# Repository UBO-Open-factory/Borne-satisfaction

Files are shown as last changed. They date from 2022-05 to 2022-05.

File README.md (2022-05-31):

# The project #
This french project consists in making a terminal with 3 push buttons that can record the data on an SD card to collect results for a satisfaction survey.

You can find the project's page on [wikifactory](https://wikifactory.com/+uboopenfactory/borne-de-satisfaction)

Last : most of the documentation is written in French...

# Directory structure #

## Electronique
You can find here the Eagles project and everything about the mother board constuction.

## Mécanique
You can find here everything about the constuction of the wood-box as Lasercut plans.

Plans are on SVG format.

## Programmation
This is where you will find the main program, tests and everything about the ESP-32 code.

Code is written in C++ Language for a Firebeetle ESP32. Please [check the documentation before compiling](./Programmation/Microcontroleur/README.md).

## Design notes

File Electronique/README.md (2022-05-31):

L'électronique de la borne de satisfaction s'articule autour de l'architecture composée :
- Une carte Firebeetle ESP32 (Processeur+Charge de la batterie) <br>
- 3 Boutons poussoirs pour le vote
- 3 Leds pour indiquer le bouton pressé au votant
- Un lecteur de carte SD et sa carte SD qui contient les résultats des votes
- Une horloge temps réelle pour indiquer l'horodatage des votes

### Architecture Principale ###
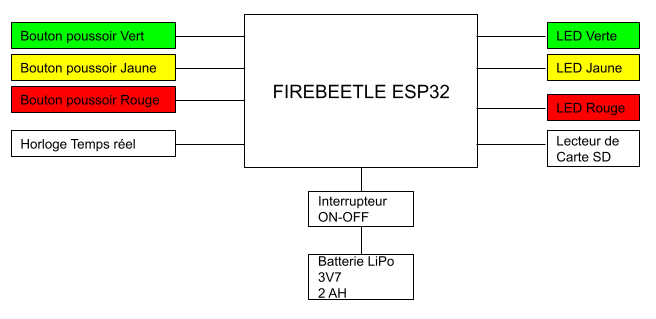
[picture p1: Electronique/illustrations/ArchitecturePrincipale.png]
Architecture Principale


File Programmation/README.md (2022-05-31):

Here you can find directories containing :

**doc** : the technical documetation of the ESP32 code (from Doxygen) in HTML format.

**Main program** : ESP32 programms

**tests** : Unit test for all the modules used on the mother board (SD card, DeepSleep, Leds, Littelfs, RTC ).

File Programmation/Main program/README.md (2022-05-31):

* TOC
{:toc}

---

# Compilation du programme #
Afin de pouvoir compiler le programme, il est nécessaire d'installer [l'IDE Arduino](https://www.arduino.cc/en/software) et les cartes ESP32.

## Installation des cartes ESP32 ##
Dans les préférences de l'IDE Arduino (Fichier>Préférences ou [Ctrl] + [,]), ajouter l'URL :
``` https://dl.espressif.com/dl/package_esp32_index.json ``` dans les URL de cartes suplémentaires (il est possible d'avoir plusieurs jeux de cartes, il faut les séparer par des virgules), comme sur l'image ci-dessous.
![Ajout des cartes ESP32](./illustrations/Arduino_preferences.png)

Ensuite, dans le menu Tools > Boards manager Recherchez "ESP32" et installez les cartes trouvées.
![Ajout des cartes ESP32](./illustrations/Arduino_ESP32.png)

Dans le menu Tools > Boards, choississez la carte **FireBeetle-ESP32**
![Choix de la carte ESP32](./illustrations/Arduino_CardChoice.png)

## Installation des librairies utiles à la compilation ##
Toutes les librairies utiles se [trouvent ici](./libs/README.md)

# Utilisation du programme #

Lors de sa première execution, le programme va générer un fichier de paramétrage vierge sur la carte SD. Une fois ce fichier modifié, vous pourrez :
- Mettre la borne à l'heure,
- Initialiser un ID pour la borne.
- Initialiser une question.

La borne est alors prète à enregistrer les réponses à la question. L'enregistrement se fait de plusieures façon dans différents fichiers stockés sur al acrte SD.

## Fichiers sur la carte SD ##
La carte SD contient plusieurs type de fichiers :
- Fichier de paramétrage (Modifiable par le **gestionnaire**)
- Fichier d'enregistrements des résultats (Généré par le programme).
- Fichier de synthèse des résultats (Généré par le programme).

### Format des fichiers ###

#### Fichier de paramétrage ####
fichier : **configuration.ini** formaté comme suit :
```
# Ceci est le fichier de configuration pour l'application 'Compteur de vote'.
# Ne modifiez pas le nom des variables (ce qui se trouve avant le signe egale sur une ligne).
# Vous pouvez modifier le texte se trouvant apres le signe egale a votre guise.
#____________________________________________________________________________________________
[config]

# Le siteID est votre identifiant comme il vous a ete donnee par l'enqueteur,
# ne le modifiez pas s'il ne vous le demande pas.
siteID=Cool Food UOF

# Cette phrase apparaitra dans le fichier resultat à votre questionnaire mais n'est pas visible sur la borne.
# Il est conseille de definir ici une phrase courte.
question=Aimez-vous faire des tests sur cette borne ?

# Si vous avez besoin de mettre la date à l'heure dans la borne, c'est ici.
# Pour la mise à l'heure, décommentez (supprimez le # en début de ligne) et 
# remplissez les champs suivant avec des valeurs numériques uniquement.
# Une fois la mise à l'heure faite, les lignes seront automatiquement commentées.
#year=2022
#month=04
#day=27
#hour=14
#minute=56
```

#### Fichier de synthèse ####
Fichier **YYYY-MM-DD_recap.txt** (par exemple 2022-04-27_recap.txt) formaté comme suit :

```
Etablissement = Cool Food I23I5V242Q
Date          = 2022/04/05
Question      = Voulez vous manger un plat végétarien une fois par semaine ?
Batterie      = 96%
Nombre d'appui sur les boutons :
  Rouge = 2
  Vert  = 4
  Jaune = 3
  TOTAL = 9
Pourcentage d'appui sur les boutons :
  Rouge = 22%
  Vert  = 44%
  Jaune = 33%

```

#### Fichiers CSV ####
Fichier **YYYY-MM-DD_detail.csv** (par exemple 2022-04-27_detail.csv) formaté comme suit :

Exemple d'un fichier 20220208_Mesures.csv

| ID du site | Date | Heure | Question | Vert | Rouge | Jaune | Niveau Batterie
| ---------- | ---- | ----- | -------- | --- | --- | ----------- | ---------------
| OpenFactory | 08/02/2022 | 12:45:52 | Aimez-vous les artichauds | 1 | 0 | 0 | 90%
| OpenFactory | 08/02/2022 | 12:45:53 | Aimez-vous les artichauds | 1 | 0 | 0 | 90%
| OpenFactory | 08/02/2022 | 12:45:55 | Aimez-vous les artichauds | 0 | 0 | 1 | 90%
| OpenFactory | 08/05/2022 | 20:12:15 | Aimez-vous les artichauds | 0 | 1 | 0 | 50%

## Codes couleur des LEDs ##
Les LEDS sont utilisées pour indiquer des alertes ou des erreurs lors de la mise sous tension de la borne.

| Couleur | Allumage LED  | Signification | Bloquant |
|---------|------|---------------|------|
| Rouge | Fixe | Carte SD manquante | Oui |
| Rouge | Clignotant | Fichier configuration manquante | Oui |
| Jaune | Bref | Niveau de batterie < 20% | Non  |
| Jaune | Clignotant | Niveau de batterie < 5% | Non  |
| Jaune | Clignotant (3x) | Echec de la mise à l'heure | Non  |
| Vert  | Clignotant (3x) | Date et heure mise à jour à partir du fichier de configuration | Non |
| Vert  | Bref | Tout est OK | Non |

## Algorithme du microcontrôleur ##
![Algorithme du microcontrôleur](./illustrations/Diagrams.png)

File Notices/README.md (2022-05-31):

Dans ce répertoire, se trouvent :
- la notice d'utilisation de la borne.
- la notice du plan de montage

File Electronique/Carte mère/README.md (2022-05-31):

## Plan carte mère ##
dans ce répertoie, se trouve tout ce qui conerne la fabrication de la carte mère fait pour le projet.

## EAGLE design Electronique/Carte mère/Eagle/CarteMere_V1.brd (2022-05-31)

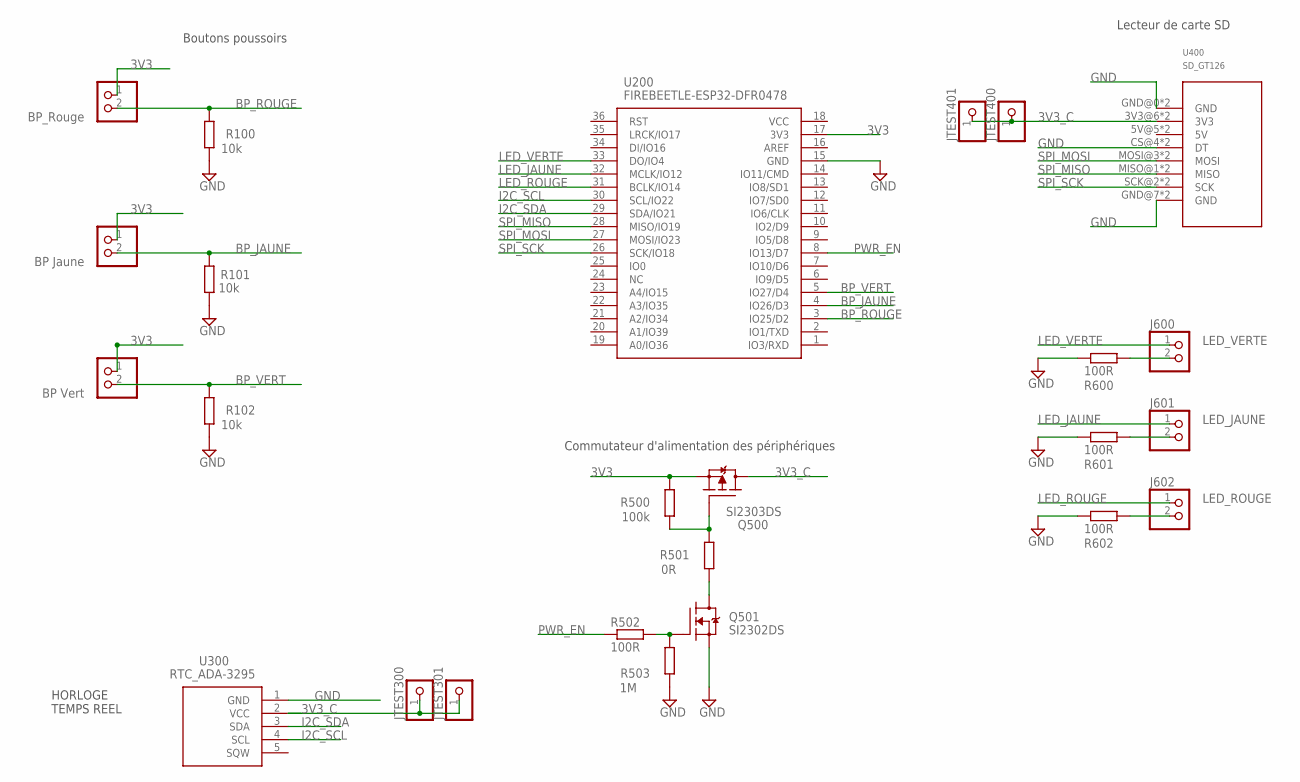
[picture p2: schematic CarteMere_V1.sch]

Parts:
J100: BP_Rouge; 1X02
J101: BP Jaune; 1X02
J102: BP Vert; 1X02
J600: LED_VERTE; 1X02
J601: LED_JAUNE; 1X02
J602: LED_ROUGE; 1X02
JTEST300, JTEST301, JTEST400, JTEST401: PINHD-1X1; 1X01
Q500: SI2303DS; SOT23
Q501: SI2302DS; SOT23
R100, R101, R102: 10k; 0207/10
R500: 100k; 0207/10
R501: 0R; 0207/10
R502, R600, R601, R602: 100R; 0207/10
R503: 1M; 0207/10
U200: FIREBEETLE-ESP32-DFR0478; FIREBEETLE_ESP32
U300: RTC_ADA-3295; ADA3295
U400: SD_GT126

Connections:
3V3: J100.1, J101.1, J102.1, Q500.2 (S), R500.2, U200.17 (3V3)
3V3_C: JTEST300.1, JTEST301.1, JTEST400.1, JTEST401.1, Q500.3 (D), U300.2 (VCC), U400.3V3@6 (3V3), U400.3V3@9 (3V3)
BP_JAUNE: J101.2, R101.2, U200.4 (IO26/D3)
BP_ROUGE: J100.2, R100.2, U200.3 (IO25/D2)
BP_VERT: J102.2, R102.2, U200.5 (IO27/D4)
DQ501: Q501.3 (D), R501.1
GND: Q501.2 (S), R100.1, R101.1, R102.1, R503.1, R600.1, R601.1, R602.1, U200.15 (GND), U300.1 (GND), U400.CS@4 (DT), U400.CS@11 (DT), U400.GND@0 (GND), U400.GND@7 (GND), U400.GND@8 (GND), U400.GND@15 (GND)
I2C_SCL: U200.30 (SCL/IO22), U300.4 (SCL)
I2C_SDA: U200.29 (SDA/IO21), U300.3 (SDA)
LED_JAUNE: J601.1, U200.32 (MCLK/IO12)
LED_ROUGE: J602.1, U200.31 (BCLK/IO14)
LED_VERTE: J600.1, U200.33 (DO/IO4)
unnamed: Q501.1 (G), R502.2, R503.2
unnamed: J600.2, R600.2
unnamed: J601.2, R601.2
unnamed: J602.2, R602.2
unnamed: Q500.1 (G), R500.1, R501.2
PWR_EN: R502.1, U200.8 (IO13/D7)
SPI_MISO: U200.28 (MISO/IO19), U400.MISO@1 (MISO), U400.MISO@14 (MISO)
SPI_MOSI: U200.27 (MOSI/IO23), U400.MOSI@3 (MOSI), U400.MOSI@12 (MOSI)
SPI_SCK: U200.26 (SCK/IO18), U400.SCK@2 (SCK), U400.SCK@13 (SCK)

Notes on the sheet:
HORLOGE TEMPS REEL
Commutateur d'alimentation des périphériques
Lecteur de carte SD
Boutons poussoirs

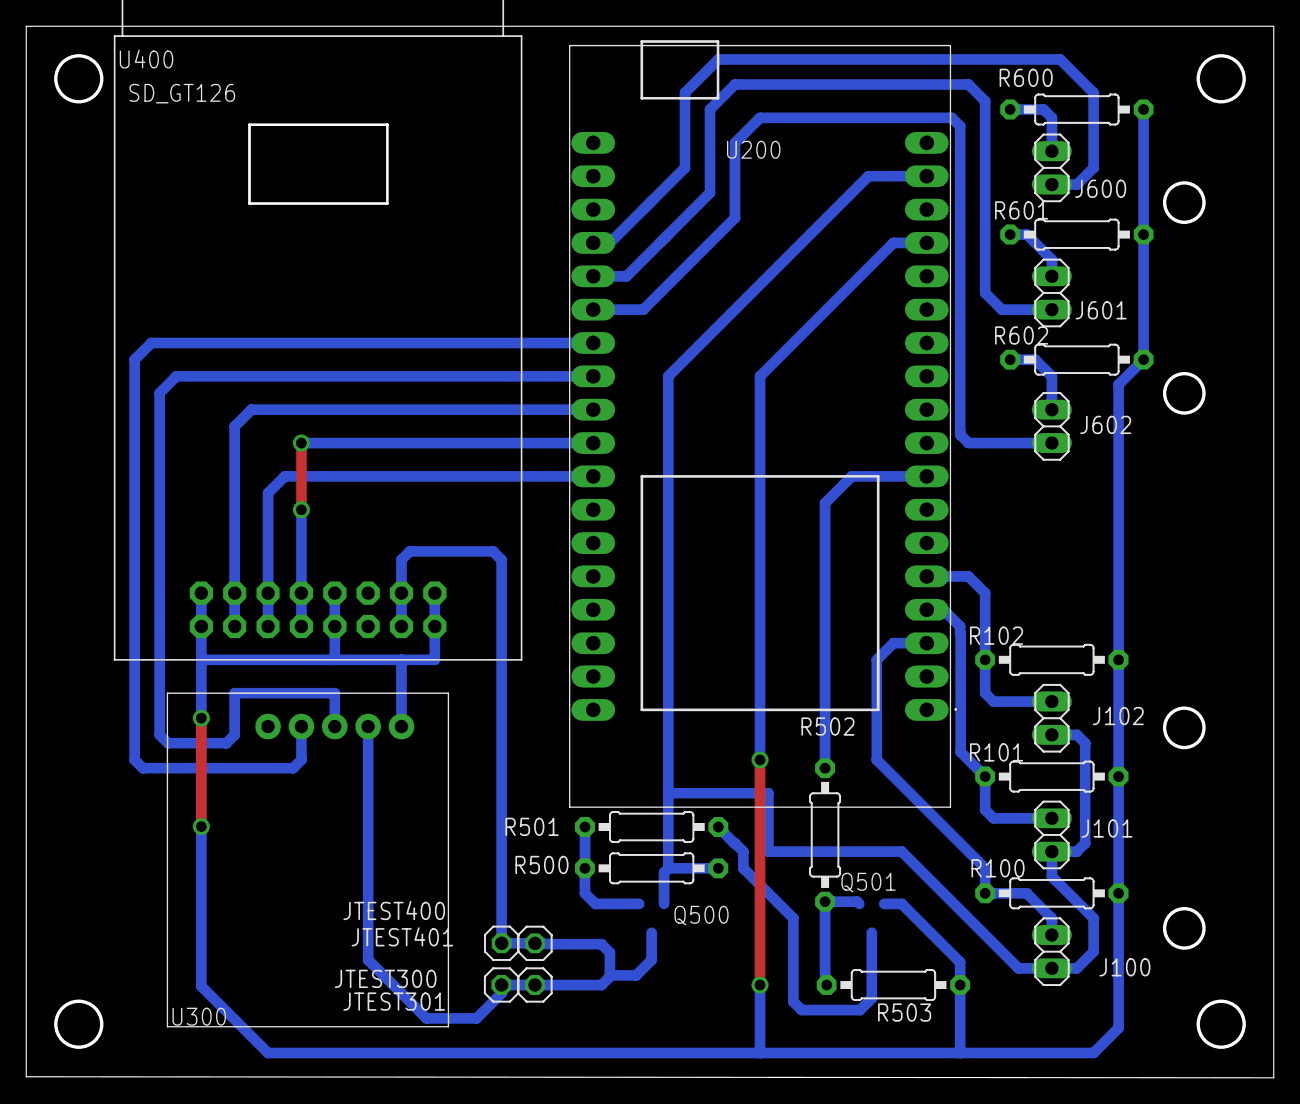
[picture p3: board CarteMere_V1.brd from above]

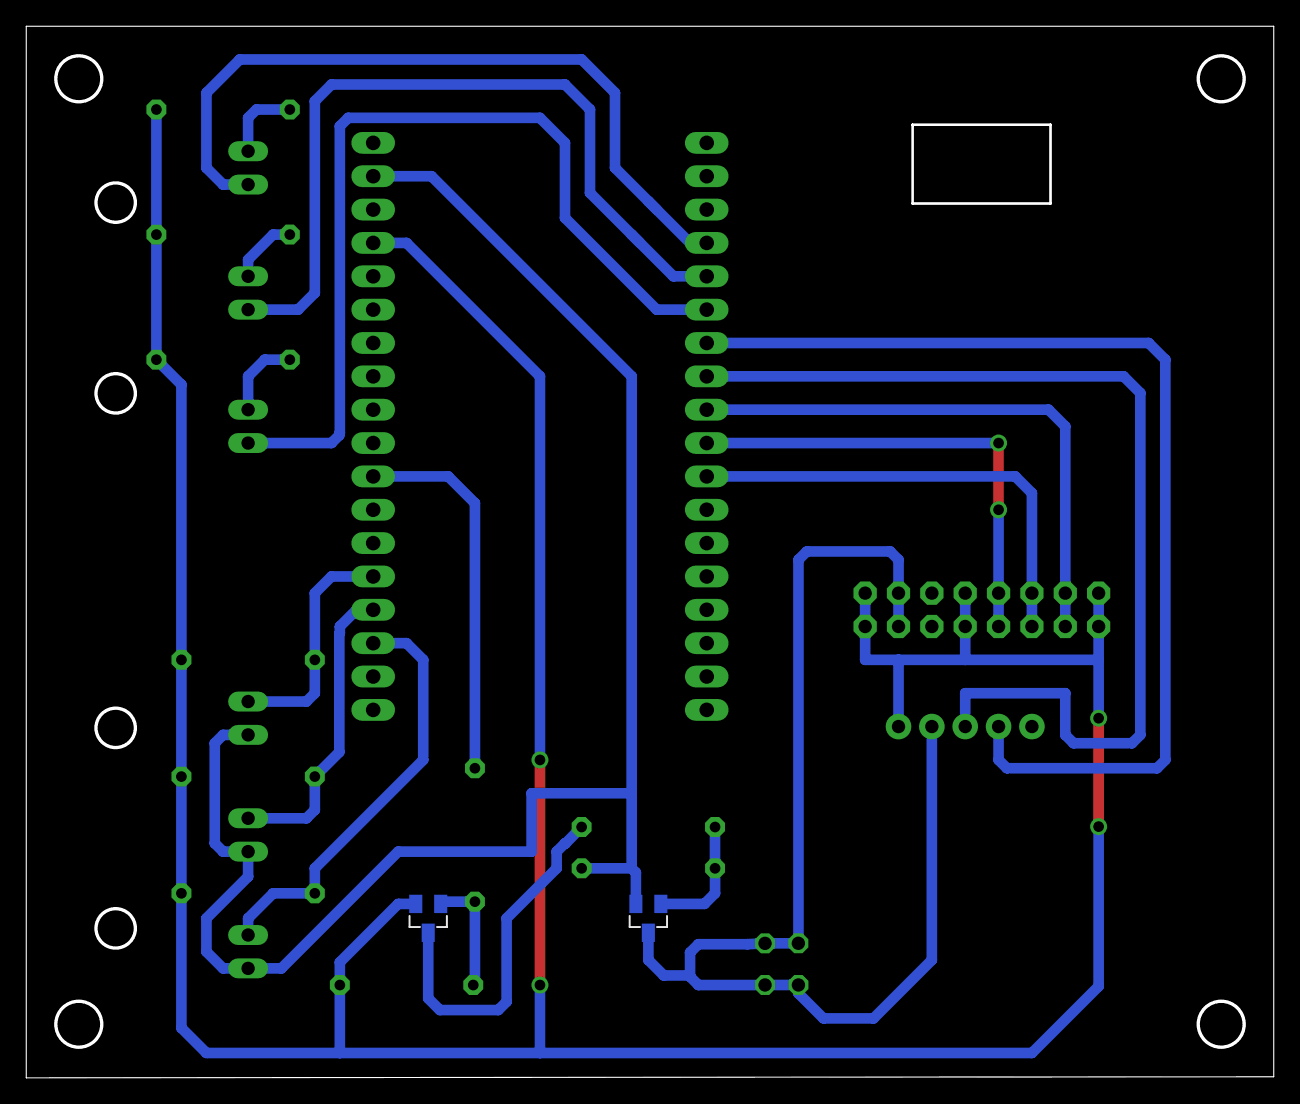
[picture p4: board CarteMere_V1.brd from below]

Board: 2 copper layers, 95.0 x 80.1 mm, 25 parts (2 on the bottom side), 21 nets.

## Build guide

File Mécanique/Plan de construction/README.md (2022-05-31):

## Plan de construction ##
Dans ce répertoie, se trouve tout ce qui concerne la construction physique.

## Epaisseurs des matériaux ##
* PMMA :
  * Dessus de la boite : 3 mm
* CTP peuplier :
  * Coté de la boite : 5 mm

## Paramétres des découpes laser ##
Ces paramètres sont valable pour la laser avec des miroirs propres.

| Matériau | Opération | Power | Speed | Remarque |
|---|---|---|---|---|
| PMMA 3 mm | Cut | 20 | 75 | |
| CTP Peuplier 5 mm | Cut | 100 | 45 | |
| CTP Peuplier 5 mm | Mark | 8 | 20 | Défocalisation à +2 mm |

## Agencement des découpes ##
Le logiciel [Deepnest](https://deepnest.io/) permet d'agencer avec un minimum de perte les différentes pièces à découper.

Dans le logiciel Deepnest :
- Importer le fichier svg.
- Cliquer sur le [+] en bas de page pour ajouter une "planche"
- Donner les dimensions en millimètres de la planche (par exemple 900 x 450), puis cliqueer sur [Add]
- Cocher la pièce nouvellement créé (elle doit être tout en bas de la liste) pour qu'elle soit défini comme "Sheet".
- Lancer la génération de l'agencement [Start Nest]
- ... et attendre ...
- Cliquer sur un des éléments dans la liste *best nests so far* des "trucs" colorés pour choisir le meilleur agencement.
(Attention à bien vérifier que toutes les pièces sont bien présentes dans l'agencement proposé -> cf *parts placed*)
- Exporter le plan de découpe au format SVG.

NB : Le logiciel Deepnest ne s'arrète jamais de calculer un meilleur agencement, il faut cliquer sur le bouton **"Stop nest"**

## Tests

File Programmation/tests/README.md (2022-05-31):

## tests ##
Dans ce répertoie, se trouve tout ce qui concerne les tests unitaires du programme du microcontroleur

| Programme | Fonctionnalité | Source |
|---|---|---|
| esp32-deep-sleep-wake-up | Test du wake up après un Deep sleep. | [microcontrollerslab](https://microcontrollerslab.com/esp32-deep-sleep-wake-up-sources-arduino-ide/) |
| leds | Test l'allumage des leds | - |
| carteSD | Test de la carte SD | [randomnerdtutorials](https://randomnerdtutorials.com/esp32-microsd-card-arduino/)
| RTC | Test de la RTC et mise à l'heure | - |
| LittleFS-ESP32c | Test du file system dans la ram disk | - |

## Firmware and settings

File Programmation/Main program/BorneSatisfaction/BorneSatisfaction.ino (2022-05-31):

/**
 * @file BorneSatisfaction.ino
 * @brief Main programm for ESP32 micro-controller
 * @details Ce programme permet de compter le nombre d'appui sur un bouton de vote.
   - La sauvegarde de chaque vote est faite dans un fichier CSV.
   - La sauvegarde du cumul de chaque vote est faite dans un fichier TXT.
 * @date 2022-05-10
 * @author Alexandre PERETJATKO (peretjatko@univ-brest.fr)
 * 
 * @version 1.0.6
 */ // ___________________________________________________________________________________

/**
 * @def ModeDeug
 * @brief Mode prod => commenter la ligne suivante
              pour faire en sorte que le port série ne soit pas initialisé, ce qui
              permet de gagner de la vitesse d'execution au boot.
 */
//#define ModeDebug


#include "initialisation.h"
#include "RTC.h"
#include "batterie.h"
#include "carteSD.h"
#include "deepsleep.h"

// Gestion des erreurs
boolean BOO_ProblemeBatterie;
boolean BOO_ProblemeCarteSD;
boolean BOO_FichierParamsManquant;
boolean BOO_Clignote;

unsigned long LNG_Timer;


void setup() {
  // -------------------------------------------------------------------------------------------------------------
  // Mise à jour de la frequence du CPU pour une meilleur longévité de la batterie
  setCpuFrequencyMhz(80);


  // -------------------------------------------------------------------------------------------------------------
  // initialisation des clignotements des LEDs pour la gestion d'erreurs.
  //
  BOO_ProblemeBatterie      = false;
  BOO_ProblemeCarteSD       = false;
  BOO_FichierParamsManquant = false;
  BOO_Clignote = false;

  int batterieLevel =  0;

  // -------------------------------------------------------------------------------------------------------------
  // initialisation de la liaison série.
  //
#ifdef ModeDebug
  Serial.begin(115200);
  delay(1000);  // On attend que le port serie soit initialisé
  DEBUG("OK, let's go _____________________________________________________________________________");
#endif

  // -------------------------------------------------------------------------------------------------------------
  // Initialisation des PIN
  //
  pinMode(LED_ROUGE,  OUTPUT);  // Pin du bouton rouge
  pinMode(LED_VERT,   OUTPUT);  // Pin du bouton vert
  pinMode(LED_JAUNE,  OUTPUT);  // Pin du bouton jaune
  pinMode(BTN_ROUGE,  INPUT_PULLUP);  // Pin du bouton rouge
  pinMode(BTN_VERT,   INPUT_PULLUP);  // Pin du bouton vert
  pinMode(BTN_JAUNE,  INPUT_PULLUP);  // Pin du bouton jaune
  pinMode(PIN_PWR_EN, OUTPUT);  // Pin de l'autorisation de l'alimentation des périphériques


  // -------------------------------------------------------------------------------------------------------------
  // Récupération de la cause du wake up
  //
  esp_sleep_wakeup_cause_t wakeupCause = esp_sleep_get_wakeup_cause();
  DEBUG("Wake up reason : " + String(wakeupCause) );



  // -------------------------------------------------------------------------------------------------------------
  // Alimentation des périphériques
  //
  digitalWrite(PIN_PWR_EN, HIGH);
  delay(20); // pour laisser à l'alimentation le temps de s'établir 20 ms mini
  SPI.begin();


  /** -------------------------------------------------------------------------------------------------------------
      A-t-on une mise sous tension ?
     (on fait les tests de bon fonctionnements)
  */
  if (wakeupCause != ESP_SLEEP_WAKEUP_EXT0
      and wakeupCause != ESP_SLEEP_WAKEUP_EXT1
      and wakeupCause != ESP_SLEEP_WAKEUP_TIMER
      and wakeupCause != ESP_SLEEP_WAKEUP_TOUCHPAD
      and wakeupCause != ESP_SLEEP_WAKEUP_ULP) {
    
    DEBUG("mise sous tension");
    
    // .......................................................................
    // Carte SD manquante
    //
    if (!SD.begin()) {
      DEBUG("Carte SD manquante");
      BOO_ProblemeCarteSD = true;

    } else {
      // .......................................................................
      // Fichier params manquant
      // (on test l'existance du fichier de configuration).
      //
      if (! CARTESD_existeFile( fileName_Config )) {
        DEBUG("Fichier params manquant");
        BOO_ProblemeCarteSD = true;
        BOO_Clignote = true;

        CARTESD_writeConfigFile( fileName_Config );

        CARTESD_EraseROMSynthese("question");

      } else {
        String siteID, question = "";
        if ( ! CARTESD_readConfigFile( fileName_Config, siteID, question ) ) {
          
          // Il y a eu un problème de lecture de fichier de config sur la carte SD
          DEBUG("Il y a eu un problème de lecture de variables dans le fichier de config sur la carte SD");

          CARTESD_writeConfigFile( fileName_Config );
          CARTESD_EraseROMSynthese("question");

          BOO_ProblemeCarteSD = true;
          BOO_Clignote = true;
        } else {

          // .......................................................................
          // on réinitialise les synthèses si la question a changée
          String question = "";
          if ( CARTESD_questionChange(question) ) {
            // Efface littelFS
            // et
            // Reinitialise les fichiers de synthese et de la question dans le LittelFS
            CARTESD_EraseROMSynthese(question);
            DEBUG("Reinitialisation des synthèses");

          } else {
            DEBUG("pas de changement dans la question");
          }

          // Lecture de la date et l'heure
          DEBUG("Lecture de la date et l'heure");
          bool erreurFormat = false;
          if ( CARTESD_updateDate(fileName_Config, erreurFormat)) {
            // initialisation de la RTC à partir du fichier de paramétrage
            DEBUG("initialisation de la RTC à partir du fichier de paramétrage");
            for ( int i = 0; i < 3; i++) {
              digitalWrite(LED_VERT, LOW);
              delay(DelayExtinctionLEDs/3);
              digitalWrite(LED_VERT, HIGH);
              delay(DelayExtinctionLEDs/3);
            }
          } else {
            if( erreurFormat ){
              DEBUG("Erreur de format de date ou d'heure dans '"+ String(fileName_Config) +"' à l'initialisation de la RTC");
              for ( int i = 0; i < 3; i++) {
                digitalWrite(LED_JAUNE, HIGH);
                delay(DelayExtinctionLEDs);
                digitalWrite(LED_JAUNE, LOW);
                delay(DelayExtinctionLEDs);
              }
            }

          }

          // Extinction LEDs
          digitalWrite(LED_VERT, LOW);
          digitalWrite(LED_JAUNE, LOW);




          // .......................................................................
          // Batterie faible
          //
          batterieLevel = BATTERIE_getBatterieLevel();
          if (batterieLevel < 20) {
            DEBUG("Batterie faible");
            BOO_ProblemeBatterie = true;

            if (batterieLevel < 5) {
              DEBUG("Batterie Tres faible");
              BOO_Clignote = true;
            }


          } else {

            // .......................................................................
            // Tout est ok
            //
            DEBUG("Tout est ok");
            // Allumage LED verte
            digitalWrite(LED_VERT, HIGH);
            delay( DelayExtinctionLEDs);


            // Deep sleep
            DEEPSLEEP_start();
          }
        }
      }
    }
  } else {
    /** -------------------------------------------------------------------------------------------------------------
       On vient de réveiller la borne en appuyant sur un des boutons
    */
    // .......................................................................
    //  Allumage de la LEDS correspondante au bouton appuyé
    int gpio = DEEPSLEEP_getGPIOWakeUp();
    int reponseVert  = 0;
    int reponseRouge = 0;
    int reponseJaune = 0;

    switch ( gpio ) {
      case BTN_VERT:
        DEBUG("Bouton vert");
        digitalWrite(LED_VERT,  HIGH);
        reponseVert = 1;
        break;

      case BTN_ROUGE:
        DEBUG("Bouton rouge");
        digitalWrite(LED_ROUGE,  HIGH);
        reponseRouge = 1;
        break;

      case BTN_JAUNE:
        DEBUG("Bouton jaune");
        digitalWrite(LED_JAUNE,  HIGH);
        reponseJaune = 1;
        break;
      default:
        DEBUG("Le GPIO " + String(gpio) + " a réveillé l'ESP32 : cas non traité (GPIO inconnu)");
    }


    // .......................................................................
    //  Lecture de la date et l'heure
    RTC_setTime();
    String date  = RTC_getDate();   // "1971/01/27";
    String heure = RTC_getTime();  // "14:06:24";



    // .......................................................................
    //  Lecture du niveau de la batterie
    batterieLevel = BATTERIE_getBatterieLevel();


    // .......................................................................
    //  Lecture du fichier de configuration
    String siteID, question = "";
    if ( CARTESD_readConfigFile( fileName_Config, siteID, question ) ) { // Initialise siteID et question
      DEBUG(siteID);
      DEBUG(question);


      // .......................................................................
      //  Ecriture dans le fichier des mesures
      String ligneFichierMesure = siteID + ";" + date + ";" + heure + ";" + question + ";"
                                  + String(reponseVert) + ";" + String(reponseRouge) + ";" + String(reponseJaune) + ";"
                                  + String(batterieLevel);
      CARTESD_appendFileMesure(date, postfixeFileMesures, ligneFichierMesure );


      // .......................................................................
      //  Mise à jour de la synthèse des votes
      CARTESD_miseAJourSynthese(postfixeFileSynthese, reponseRouge, reponseVert, reponseJaune, batterieLevel, date, question, siteID);
      delay( DelayExtinctionLEDs );


      // .......................................................................
      //  Extinction des LEDs
      digitalWrite(LED_ROUGE, LOW);
      digitalWrite(LED_VERT,  LOW);
      digitalWrite(LED_JAUNE, LOW);


      // .......................................................................
      // Deep sleep
      DEEPSLEEP_start();


    } else {
      // Lecture impossible du fichier de paramétrage
      DEBUG("Lecture impossible du fichier de paramétrage : Carte SD arrachée ?");
      BOO_ProblemeCarteSD = true;
    }
  }

  // Timer pour le clignottement des leds
  LNG_Timer = millis();
}



/**
 * ****************************************************************************************************************
 * ****************************************************************************************************************
   Boucle principale.
   On n'entre à l'interieur que pour la gestion des erreurs au démarrage du boitier de vote.
*/
void loop() {

  // SI LE TIMER EST DÉPASSÉ .............................................................
  if( LNG_Timer + DelayExtinctionLEDs < millis() ){
    // Allumage/Extinction led ROUGE
    if ( BOO_ProblemeBatterie ) {
      DEBUG("ProblemeBatterie -> JAUNE");
      if( BOO_Clignote ) {
        digitalWrite(LED_JAUNE, ! digitalRead(LED_JAUNE) );
        DEBUG("Clignotement JAUNE");
      } else {
        digitalWrite(LED_JAUNE, HIGH );
      }
    }

    // Allumage/Extinction  led JAUNE
    if ( BOO_ProblemeCarteSD ) {
      DEBUG("ProblemeCarteSD -> ROUGE");
      if( BOO_Clignote ) {
        digitalWrite(LED_ROUGE, ! digitalRead(LED_ROUGE) );
        DEBUG("Clignottement ROUGE");
      } else {
        digitalWrite(LED_ROUGE, HIGH );

      }
    }
    // Réinitilaisation du timer
    LNG_Timer = millis();
  }


  // SI ON APPUI SUR UN BOUTON ...........................................................
  if( digitalRead(BTN_JAUNE) == HIGH or digitalRead(BTN_ROUGE) == HIGH or digitalRead( BTN_VERT) == HIGH ){
    DEBUG("Alarme acquitée. On reboot");

    delay(DelayExtinctionLEDs);

    // Deep sleep
    DEEPSLEEP_start();
  }
}

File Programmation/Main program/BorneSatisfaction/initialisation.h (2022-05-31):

/**
 * @file initialisation.h
 * @brief Every globale variables are initiate here.
 * 
 * @author Alexandre PERETJATKO
 */

// Definition des noms des fichiers
// La synthese et les mesuress seront modifiés avec la date courante.

/** Config file name */
char *fileName_Config       = "/configuration.ini";

/** End of syntheses file name (Date will be postfix */
char *postfixeFileSynthese  = "_recap.txt";

/** End of detail file name (Date will be postfix */
char *postfixeFileMesures   = "_detail.csv";



// Brochage des PIN
#define LED_VERT  4
#define LED_JAUNE 12
#define LED_ROUGE 14

#define BTN_ROUGE 25
#define BTN_JAUNE 26
#define BTN_VERT  27

#define PIN_PWR_EN 13


/** Extinction delay for LEDs when the box is turn ON and there are some error messages */
const int DelayExtinctionLEDs = 1000;

/**
 * @brief Macro d'affichage de chaines (compilée seulement en mode debug)
 * Le mode débug est mis lorsque \b ModeDebug est défini dans BorneSatisfaction.ino
 * @see BorneSatisfaction.ino
 * @def DEBUG
 */
#ifdef ModeDebug
#define DEBUG(message) \
  Serial.print("[DEBUG:"); \
  Serial.print(__func__); \
  Serial.print("("); \
  Serial.print(__LINE__); \
  Serial.print(")]-> "); \
  Serial.println(message);
#else
#define DEBUG(message);
#endif
